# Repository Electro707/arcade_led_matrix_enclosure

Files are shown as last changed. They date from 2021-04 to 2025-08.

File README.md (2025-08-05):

# Arcade Style LED Matrix Enclosure

This enclosure is for an LED matrix (2x 8x8 modules), 1 buttons, and some microcontroller (Arduino Nano for example) packaged in the shape of an arcade game.

As of right now Rev1.0 is released.

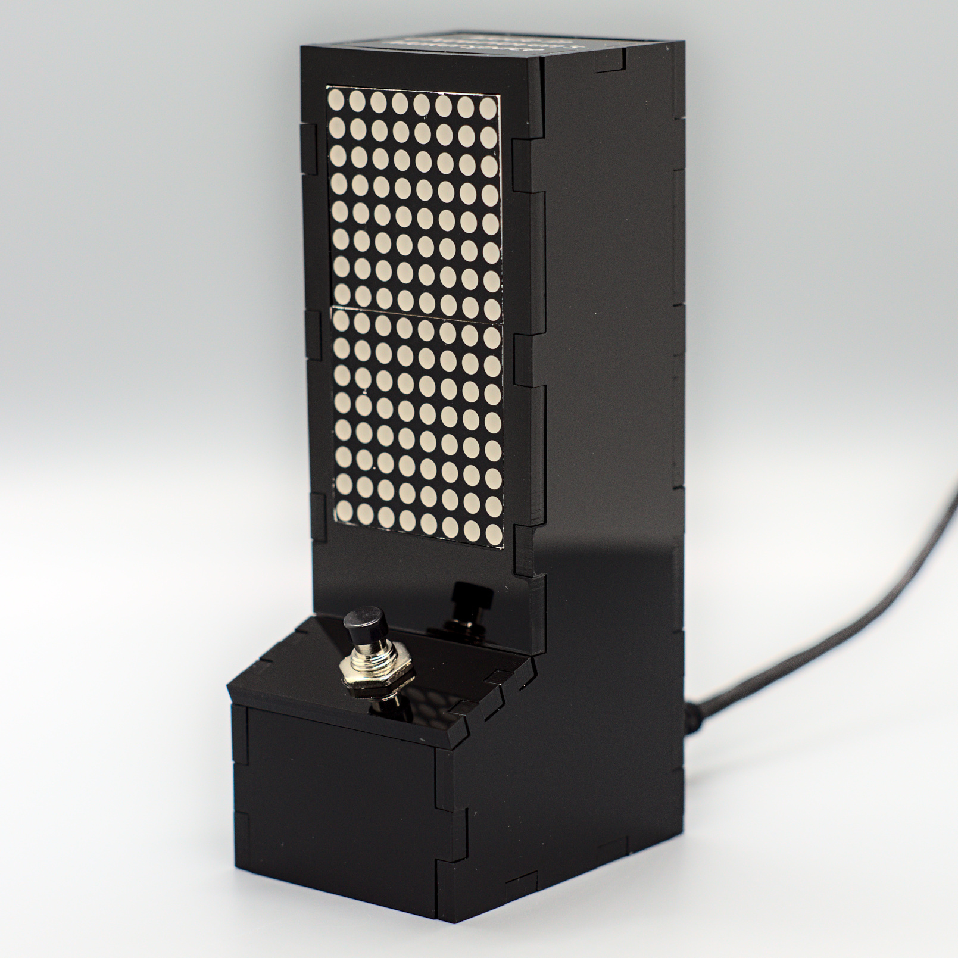
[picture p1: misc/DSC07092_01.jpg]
rev1_image


### Assembly Instructions
The assembly instructions for this enclosure can be found in [Assembly.pdf](Assembly.pdf)

### BOM:
The following BOM represents the items, other than the laser cut acrylic pieces, required to make this arcade:

| Item | Purchase Link |
| ---- | ---- |
| Arduino Nano | <ul><li>[https://www.taydaelectronics.com/nano-3-0-controller-compatible-with-arduino-nano-ch340-usb-driver.html](https://www.taydaelectronics.com/nano-3-0-controller-compatible-with-arduino-nano-ch340-usb-driver.html)</li><li>[https://www.amazon.com/REXQualis-Board-ATmega328P-Compatible-Arduino/dp/B07WK4VG58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](https://www.amazon.com/REXQualis-Board-ATmega328P-Compatible-Arduino/dp/B07WK4VG58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)</li></ul> |
| 7mm momentary Button | <ul><li>[https://www.taydaelectronics.com/electromechanical/switches-key-pad/pb-11d02-push-button-panel-mount-spst-no-pb-11d02-th1r00.html](https://www.taydaelectronics.com/electromechanical/switches-key-pad/pb-11d02-push-button-panel-mount-spst-no-pb-11d02-th1r00.html)</li><li>[https://www.amazon.com/DIYhz-Normal-Momentary-Switch-Button/dp/B07BD2D96W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](https://www.amazon.com/DIYhz-Normal-Momentary-Switch-Button/dp/B07BD2D96W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)</li></ul> |
| MAX7219 LED Matrix (cut to 16x8) | <ul><li>[https://www.amazon.com/ALAMSCN-MAX7219-Display-Raspberry-Microcontroller/dp/B08KS68GYZ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](https://www.amazon.com/ALAMSCN-MAX7219-Display-Raspberry-Microcontroller/dp/B08KS68GYZ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)</li></ul> |
| 2.54 mm header | <ul><li>[https://www.taydaelectronics.com/connectors-sockets/pin-headers/40-pin-2-54-mm-single-row-pin-header-strip.html](https://www.taydaelectronics.com/connectors-sockets/pin-headers/40-pin-2-54-mm-single-row-pin-header-strip.html)</li><li>[https://www.amazon.com/Header-Lystaii-Pin-Connector-Electronic/dp/B06ZZN8L9S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](https://www.amazon.com/Header-Lystaii-Pin-Connector-Electronic/dp/B06ZZN8L9S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)</li></ul> |
| Female-Female Jumper Cable | <ul><li>[https://www.taydaelectronics.com/connectors-sockets/jumper-wire-dupont/premium-jumper-wires-female-female-300mm-pack-of-40.html](https://www.taydaelectronics.com/connectors-sockets/jumper-wire-dupont/premium-jumper-wires-female-female-300mm-pack-of-40.html)</li><li>[https://www.amazon.com/Premium-Breadboard-Jumper-100-Pack-Hellotronics/dp/B07GJDJ96Z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](https://www.amazon.com/Premium-Breadboard-Jumper-100-Pack-Hellotronics/dp/B07GJDJ96Z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)</li></ul> |

###### Note: I am not sponsored by the purchase links above, neither do I necessarily endorse them. They are the first items that showed up when I searched for them on Amazon and TaydaElectronics. The parts are generic enough where there should be available everywhere including Amazon, Ebay, TaydaElectronics, AliExpress, and many other sellers.

### Acrylic Pieces:

You will need some kind of laser cutter to laser-cut the acrylic pieces for assembly. The acrylic must be 1/8in thick (unless that is changed in the CAD file).

An SVG has been made with all pieces on it, which can found in [SVG_Pieces_Drawing.svg](SVG_Pieces_Drawing.svg). It should be scaled correctly so it can be sent to a laser cutter without any modification.

While you can 3D print the pieces, it is not recommended as A) This enclosure wasn't designed with FDM manufacturing in mind, otherwise I would have done it differently, and B) The slots are toleranced negatively (so the slots are wider than the holes) due to how laser cutting acrylic melts some of the material.

### Software

The software on the Arduino can be anything you want it to be, so go nuts! 

As of right now there is only 1 game written for it by me, which is a basic stacker game. The game can be found at [https://github.com/Electro707/arduino_matrix_arcade_stacker](https://github.com/Electro707/arduino_matrix_arcade_stacker)

### TODO:
- [x] Finish up reference dimensions from the spreadsheet
- [x] Lower the tolerances on some of the slots (too tight but usable when tested)
- [x] Create an assembly instructions/diagram

### Credits:
- Arduino Nano Model: [https://grabcad.com/library/arduino-nano-ch430g-1](https://grabcad.com/library/arduino-nano-ch430g-1)

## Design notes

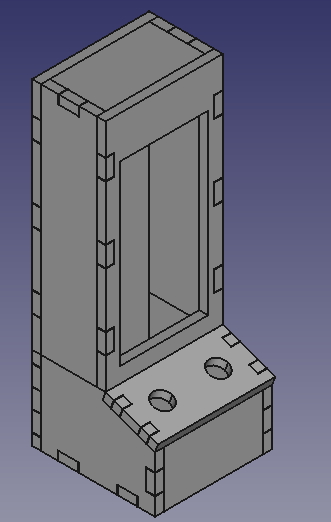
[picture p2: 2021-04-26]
misc/Screenshot_20210426_161534.png

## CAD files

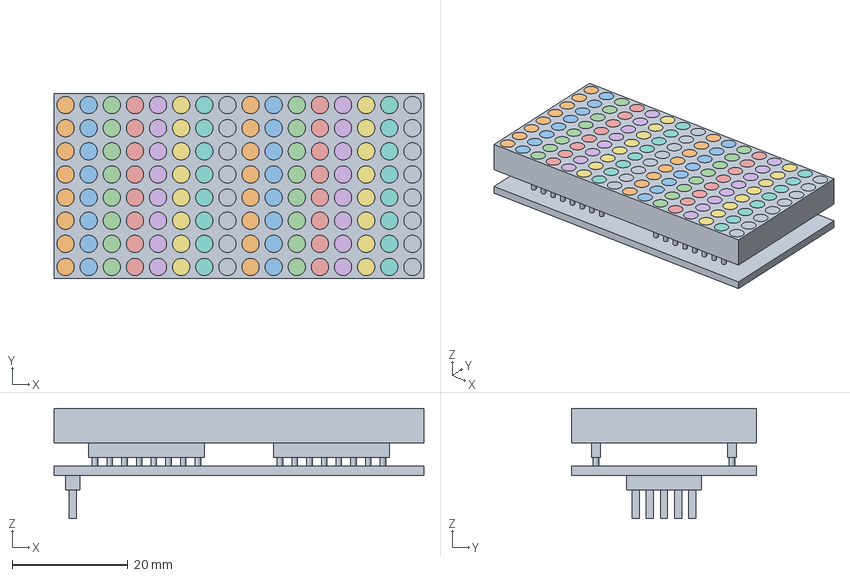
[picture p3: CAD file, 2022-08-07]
assembly/2led_matrix.FCStd
64.0 x 32.0 x 19.1 mm
Circle
Circle001
Circle002
Circle003
Circle004
Circle005
Circle006
Circle007
Circle008
Circle009
Circle010
Circle011
Circle012
Circle013
Circle014
Circle015
Circle016
Circle017
Circle018
Circle019
Circle020
Circle021
Circle022
Circle023
Circle024
Circle025
Circle026
Circle027
Circle028
Circle029
Circle030
Circle031
Circle032
Circle033
Circle034
Circle035
Circle036
Circle037
Circle038
Circle039
Circle040
Circle041
Circle042
Circle043
Circle044
Circle045
Circle046
Circle047
Circle048
Circle049
Circle050
Circle051
Circle052
Circle053
Circle054
Circle055
Circle056
Circle057
Circle058
Circle059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

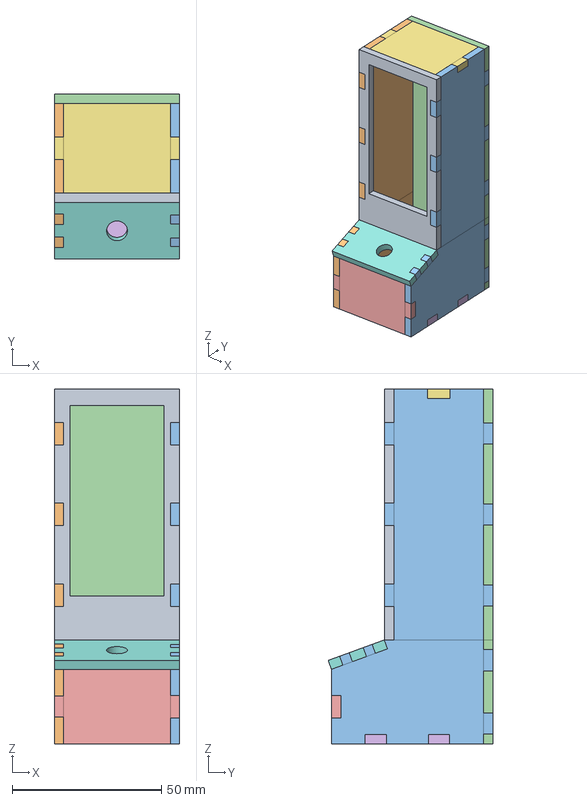
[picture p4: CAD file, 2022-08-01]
Enclosure.FCStd
42.0 x 55.1 x 118.8 mm
Matrix_Front
Left_Side
Right_Side
Back_Cover
Front_Cover
Bottom_Cover
Top_Cover
1_Button_Cover

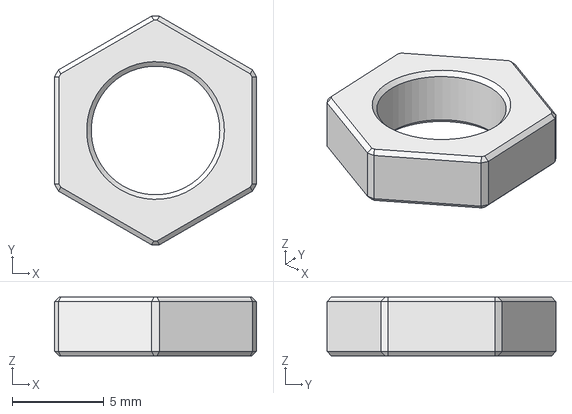
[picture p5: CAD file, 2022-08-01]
assembly/M7Nut.FCStd
11.0 x 12.5 x 3.20 mm

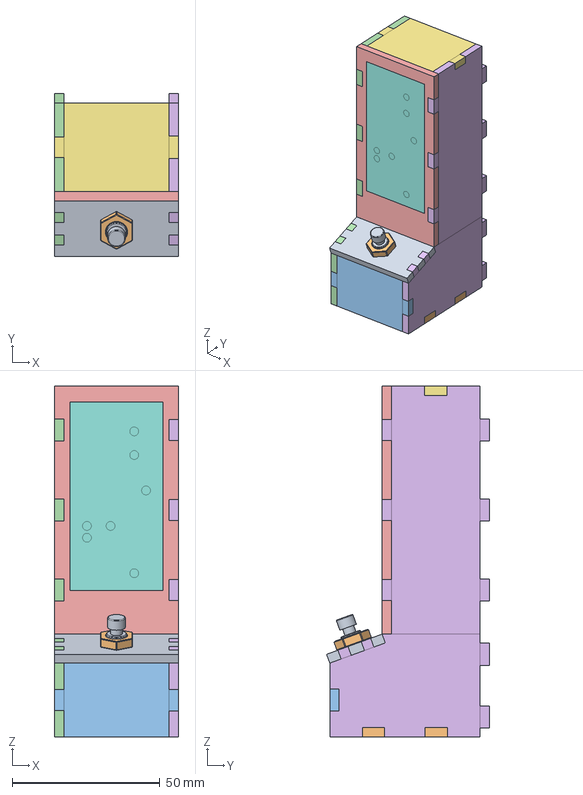
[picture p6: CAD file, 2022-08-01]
assembly/base.FCStd
42.0 x 55.1 x 118.8 mm
Enclosure_1_Button_Cover_001
Enclosure_Bottom_Cover_001
Enclosure_Front_Cover_001
Enclosure_Left_Side_001
Enclosure_Matrix_Front_001
Enclosure_Right_Side_001
Enclosure_Top_Cover_001
2led_matrix_001
7mm_momentary_push_001
M7Nut_001

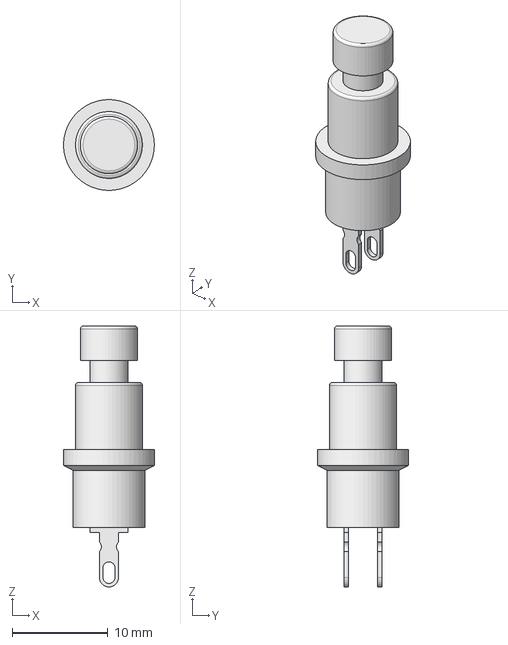
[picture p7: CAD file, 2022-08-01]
assembly/7mm_momentary_push.FCStd
9.49 x 9.50 x 27.3 mm

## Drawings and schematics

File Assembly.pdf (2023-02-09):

# Stacker Mini-Arcade Build Instructions

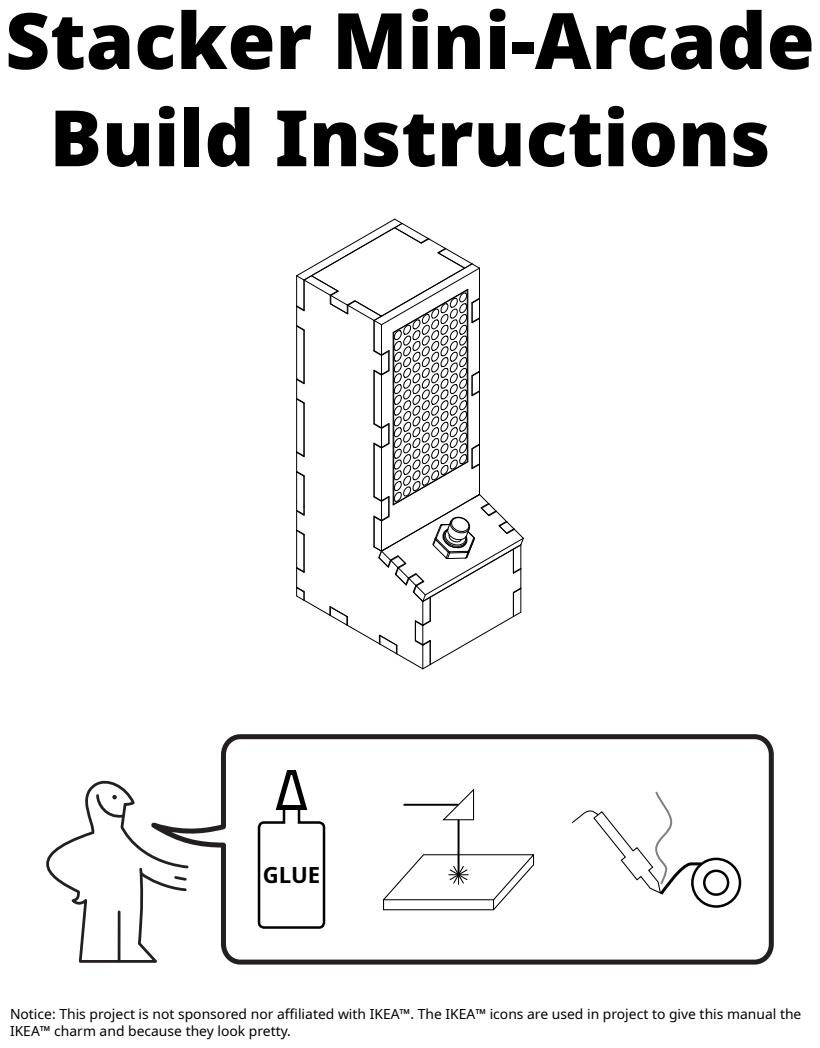
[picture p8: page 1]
GLUE

Notice: This project is not sponsored nor affiliated with IKEA™. The IKEA™ icons are used in project to give this manual the
IKEA™ charm and because they look pretty.

1
2

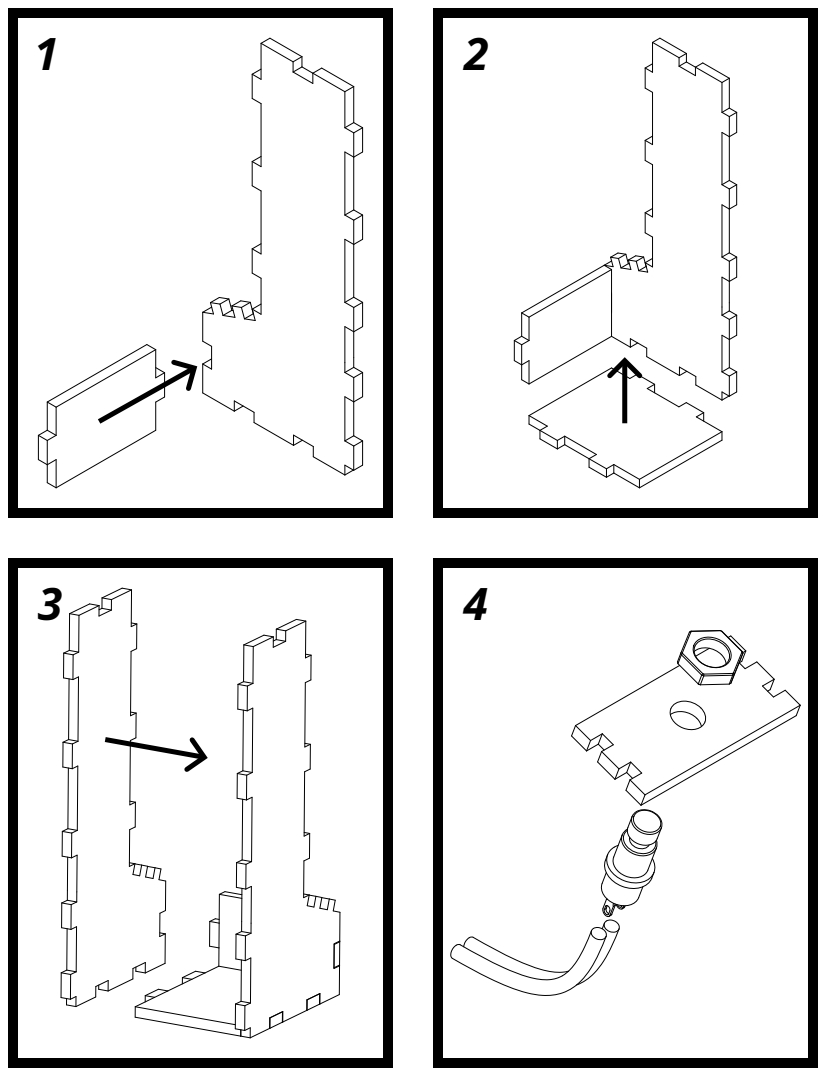
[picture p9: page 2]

5 6

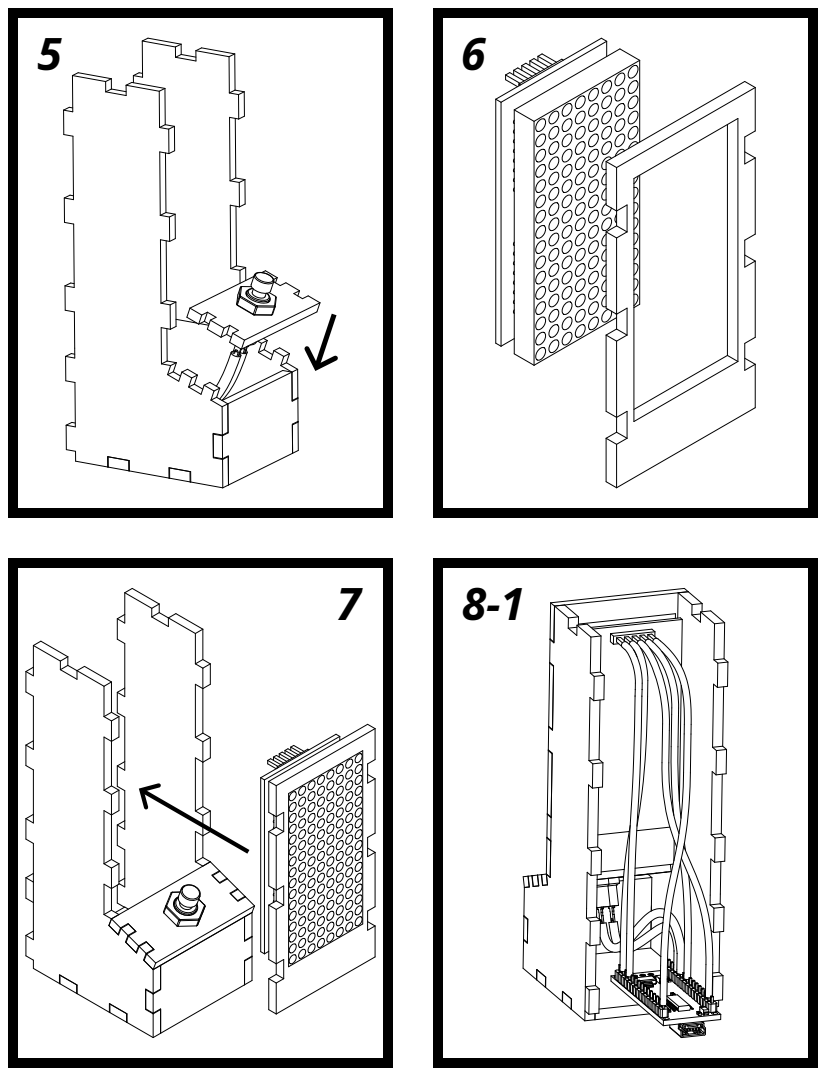
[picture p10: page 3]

8-2 | 9

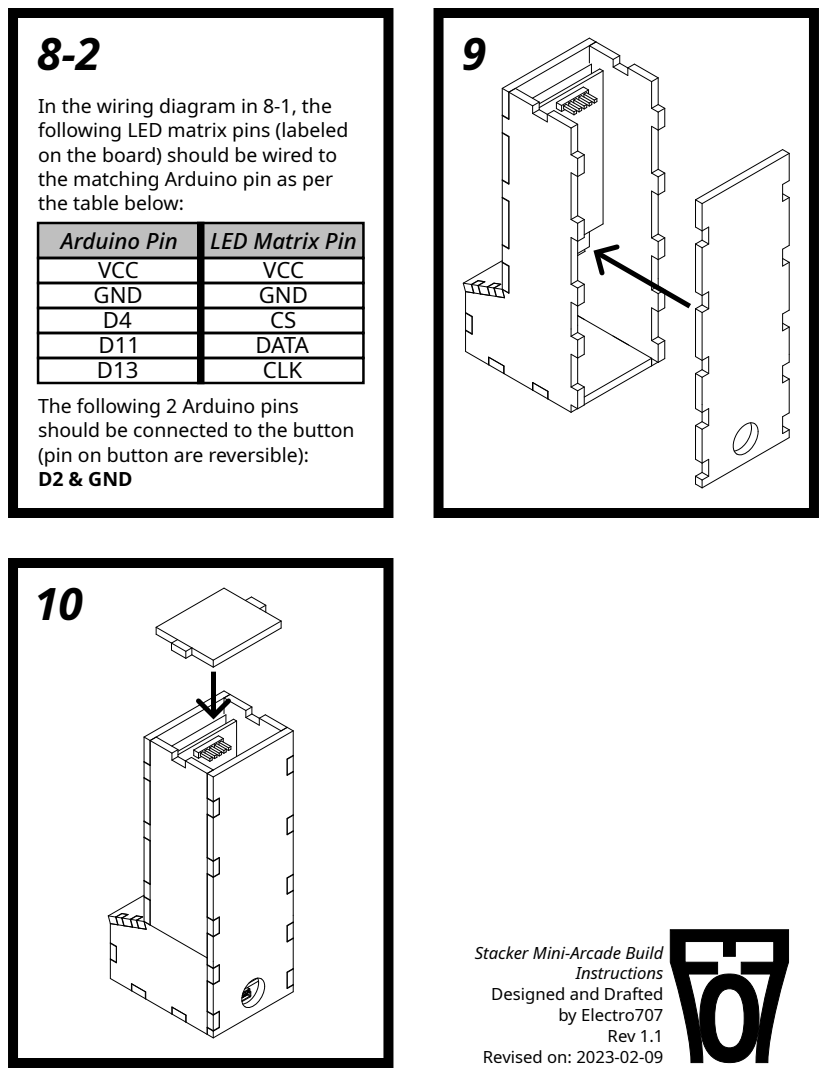
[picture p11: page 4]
Instructions; Revised on: 2023-02-09

In the wiring diagram in 8-1, the
following LED matrix pins (labeled
on the board) should be wired to
the matching Arduino pin as per
the table below:

Arduino Pin | LED Matrix Pin
VCC | VCC
GND | GND
D4 | CS
D11 | DATA
D13 | CLK

The following 2 Arduino pins
should be connected to the button
(pin on button are reversible):
D2 & GND

Stacker Mini-Arcade Build
Designed and Drafted
by Electro707
Rev 1.1

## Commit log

2021-04-26 Initial Commit. Added README.md, LICENSE.md, and the FreeCAD file
    [Enclosure.FCStd]
2021-04-28 Finished up spreadsheet/relative dimentional referencing
    [Enclosure.FCStd]
2021-05-04 Changed body names. Added a 1-button cover
    [Enclosure.FCStd]
2021-05-10 Added more dimensions to the Spreadsheet instead of a hard-coded dimension. Fixed tollerance to a losser 0.45mm
    [Enclosure.FCStd]
2021-05-10 Changed spreadsheet numbers to mm in units. Deleted 2DFaceViews
    [Enclosure.FCStd]
2022-08-01 Added some initial instructions
    [2led_matrix.FCStd, 7mm_momentary_push.FCStd, Enclosure.FCStd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]
2022-08-01 Started an update on the instructions to include an M7 nut
    [2led_matrix.FCStd, M7Nut.FCStd, base.FCStd]
2022-08-07 More complete instructions
    [2led_matrix.FCStd]
2023-02-09 Added new 8-2 instruction panel: For specifying which pin connects between the Arduino, LED matrix, and buttons
